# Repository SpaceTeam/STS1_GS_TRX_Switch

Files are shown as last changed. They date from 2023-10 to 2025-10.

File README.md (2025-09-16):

# Ground Station TRX Switch

This boards provides sequencing and switching for transmit and receive path of a satellite groundstation based on two galvanically isolated inputs.  
It features an on-board LNA with filter and pre and post filtering for an external power amplifier.  
It also provides ~30V switched for the PA derived from one common 48V supply.

It is controlled by an Arduino Nano which is used for timing.
It features two high-side MOSFET outputs for enabling a PA and LNA and three coaxial relays for RX/TX switching and antenna grounding (when neither RX nor TX is enabled).

The design was built for around 435MHz but probably is easy to adapt to different frequencies up to 3GHz.

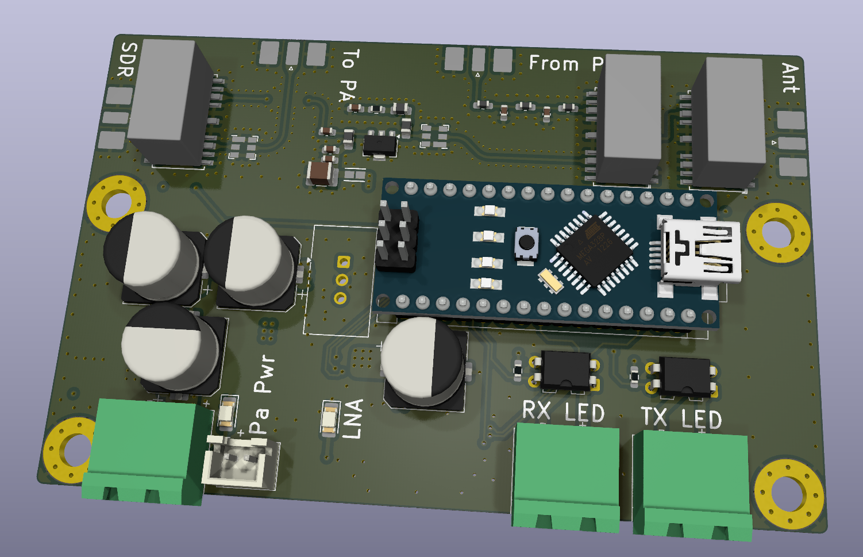
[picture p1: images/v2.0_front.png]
v2.0 Front side 3D render

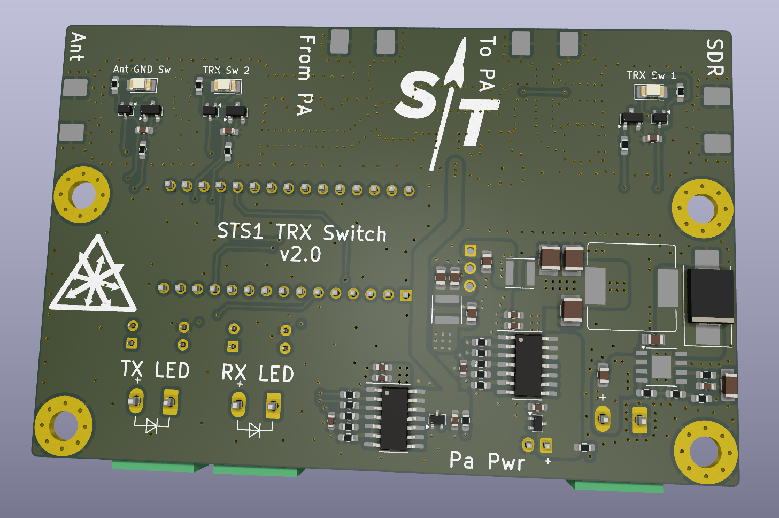
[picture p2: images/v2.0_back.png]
v2.0 Back side 3D render


## Ordering

The RF design is built for the "standard" 1.6mm thick JLCPCB 4-layer stackup consisting of the following layers:
- 35µm Outer copper
- 210.4µm Prepreg (7628, RC 49%, 8.6mil)
- 15.2µm Inner copper
- 1.065mm Core
- 15.2µm Inner copper
- 210.4µm Prepreg (7628, RC 49%, 8.6mil)
- 35µm Outer copper

For finish please choose ENIG.

## License
All files in this repository are licensed under the MIT license EXCEPT for the files in the `/3d` directory.

- Arduino Nano: By Andrew Whitham (https://grabcad.com/library/arduino-nano--1), noncommercial public use allowed (https://help.grabcad.com/article/246-how-can-models-be-used-and-shared?locale=en)
- TE HF3-53: Copyright TE Connectivity (https://www.te.com/usa-en/product-1462051-2.html)
- Molex 73251-2120: Copyright Molex LLC (https://www.molex.com/en-us/products/part-detail/0732512120)

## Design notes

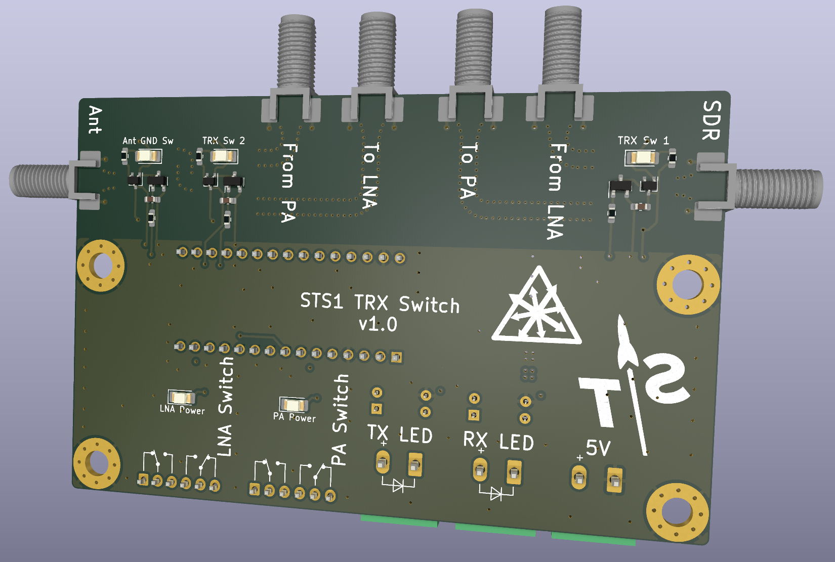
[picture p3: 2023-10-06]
images/v1.0_back.png

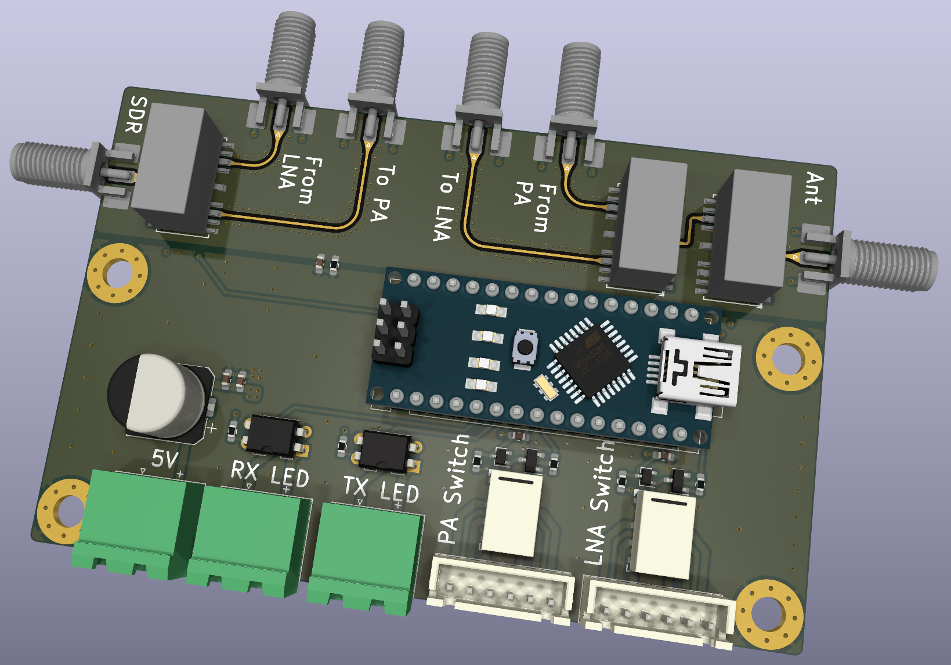
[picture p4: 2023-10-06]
images/v1.0_front.png

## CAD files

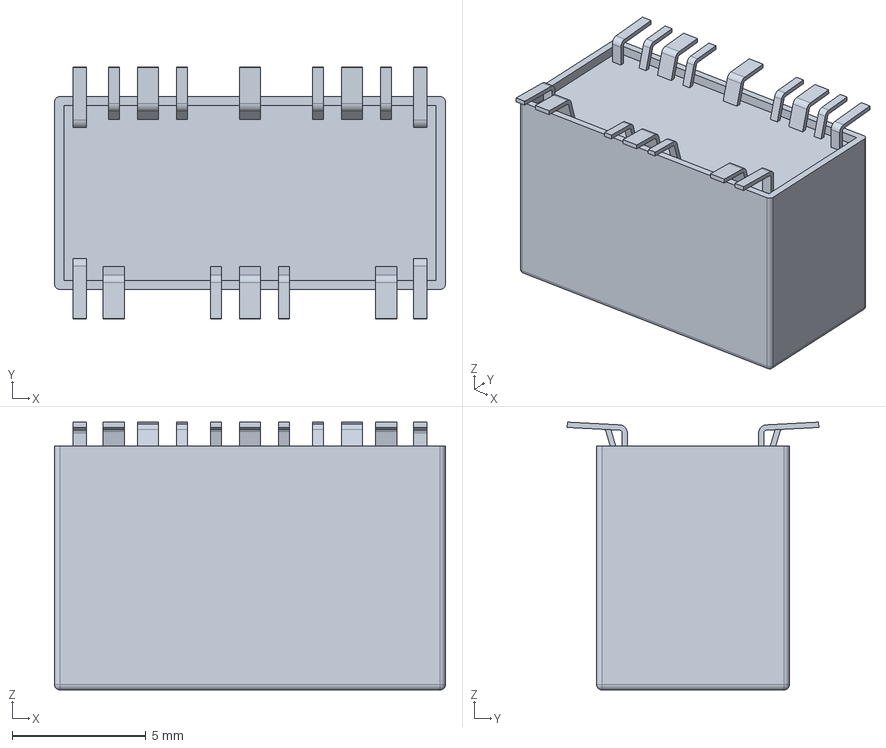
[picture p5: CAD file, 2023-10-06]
3d/TE_HF3-53.stp
14.6 x 9.40 x 10.0 mm

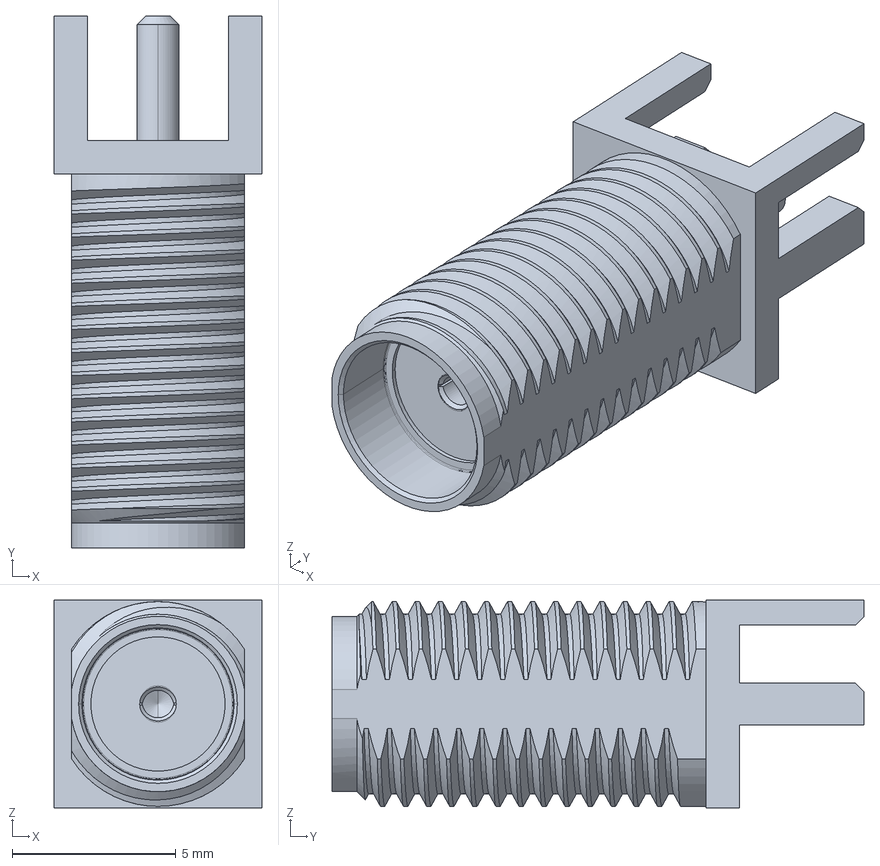
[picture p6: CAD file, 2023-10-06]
3d/Molex_732512120.stp
6.35 x 16.3 x 6.35 mm

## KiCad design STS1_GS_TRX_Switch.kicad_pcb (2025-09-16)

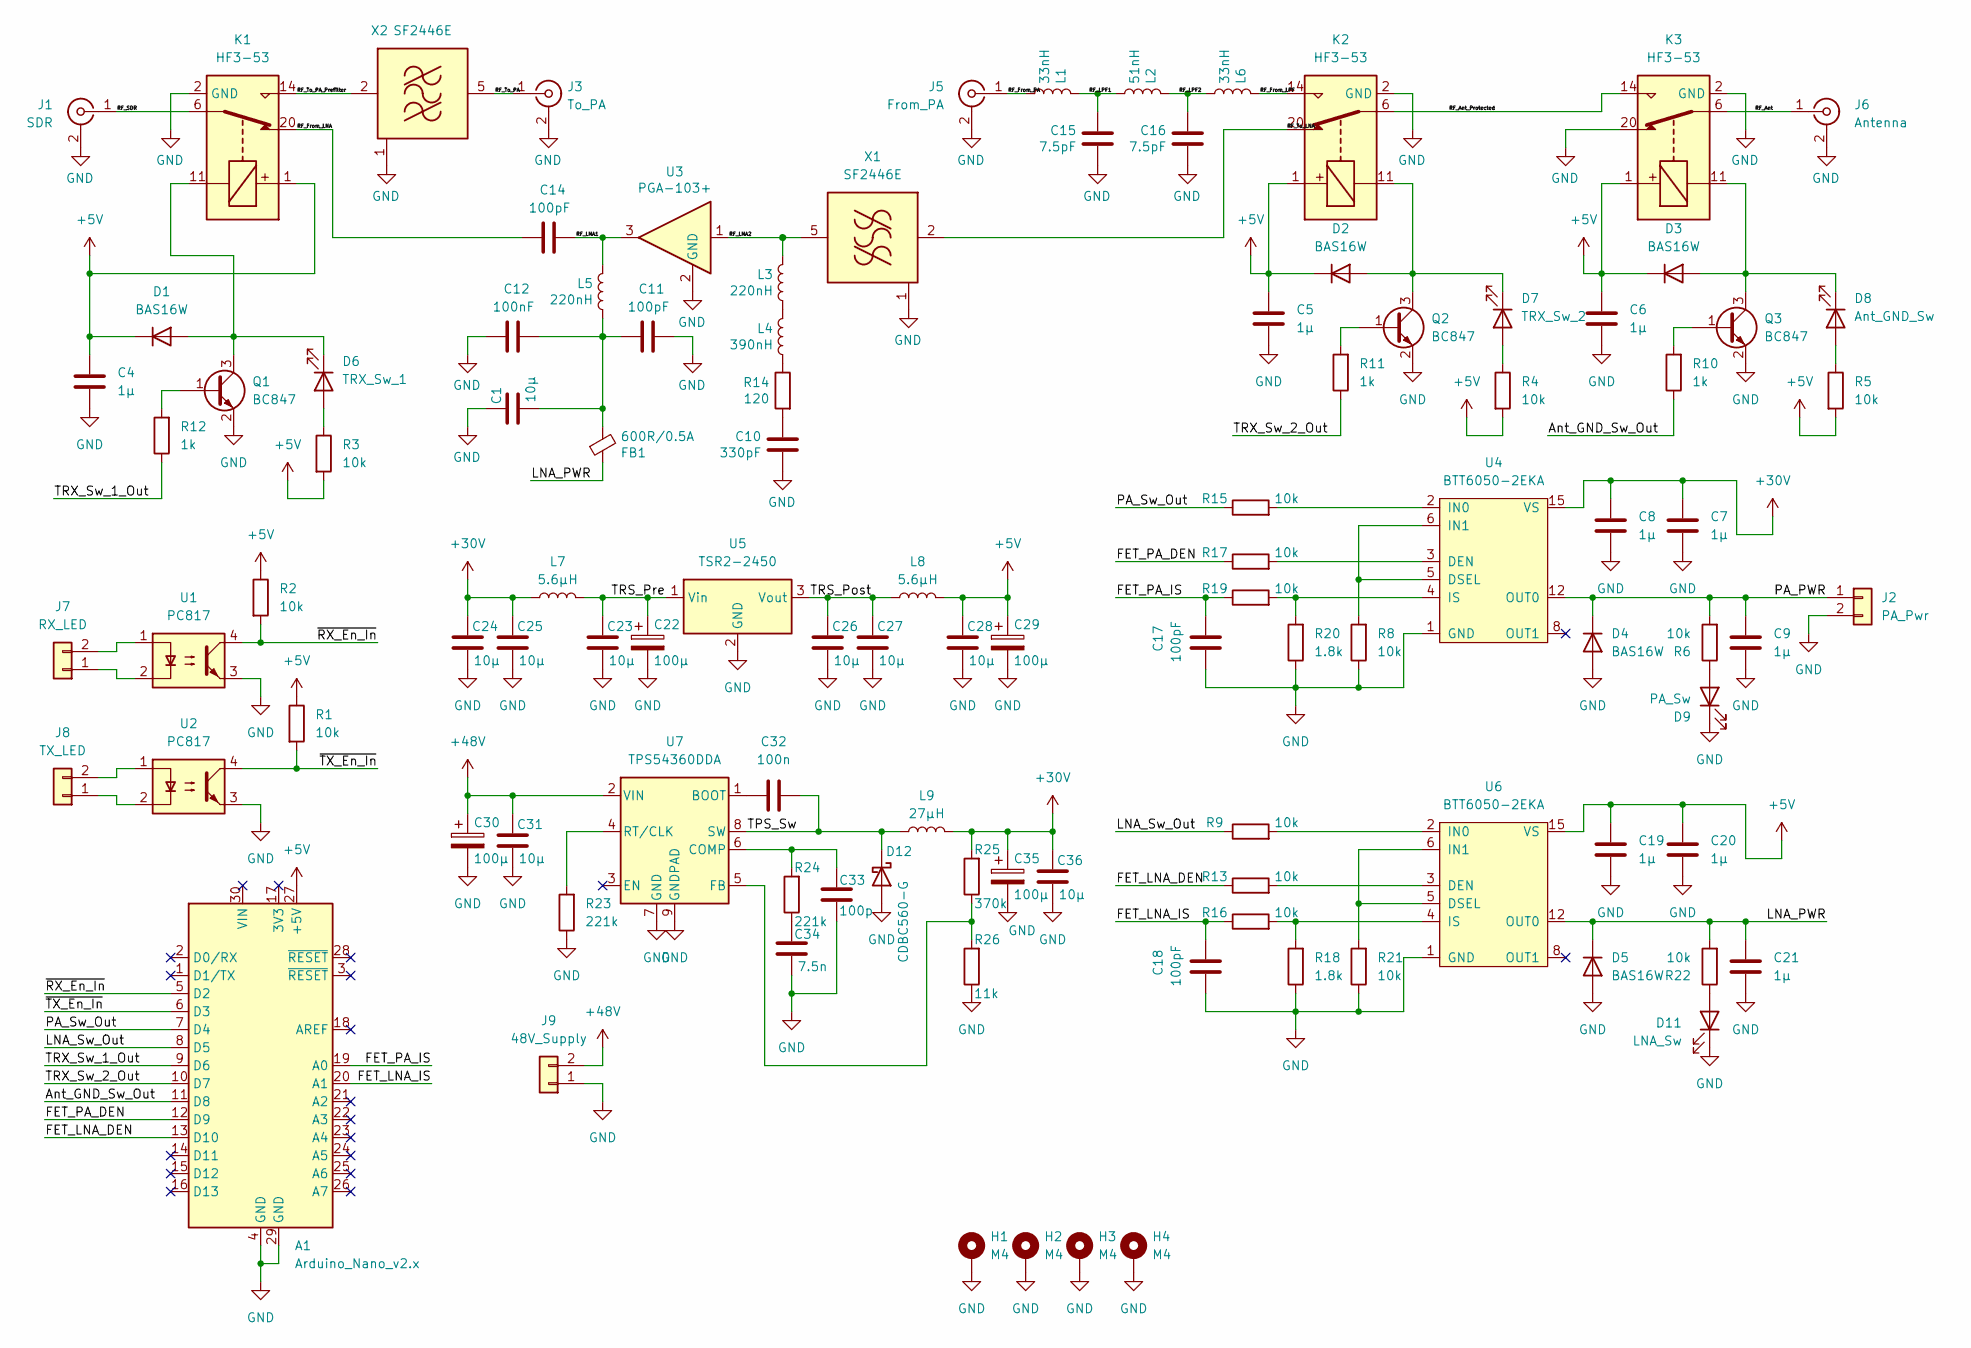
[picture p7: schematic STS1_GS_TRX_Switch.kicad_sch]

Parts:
A1: Arduino_Nano_v2.x; Arduino_Nano
C1, C24, C25, C36: 10µ; C_1210_3225Metric_Pad1.33x2.70mm_HandSolder
C4, C5, C6, C7, C8, C9, C19, C20, C21: 1µ; C_0603_1608Metric_Pad1.08x0.95mm_HandSolder
C10: 330pF; C_0603_1608Metric
C11, C14, C17, C18: 100pF; C_0603_1608Metric
C12: 100nF; C_0603_1608Metric
C15, C16: 7.5pF; C_0603_1608Metric
C22, C29, C30, C35: 100µ; CP_Elec_10x10
C23, C26, C27, C28, C31: 10µ; C_0805_2012Metric_Pad1.18x1.45mm_HandSolder
C32: 100n; C_0805_2012Metric_Pad1.18x1.45mm_HandSolder
C33: 100p; C_0603_1608Metric_Pad1.08x0.95mm_HandSolder
C34: 7.5n; C_1206_3216Metric_Pad1.33x1.80mm_HandSolder
D1, D2, D3, D4, D5: BAS16W; SOT-323_SC-70
D6: TRX_Sw_1; LED_1206_3216Metric_Pad1.42x1.75mm_HandSolder
D7: TRX_Sw_2; LED_1206_3216Metric_Pad1.42x1.75mm_HandSolder
D8: Ant_GND_Sw; LED_1206_3216Metric_Pad1.42x1.75mm_HandSolder
D9: PA_Sw; LED_1206_3216Metric_Pad1.42x1.75mm_HandSolder
D11: LNA_Sw; LED_1206_3216Metric_Pad1.42x1.75mm_HandSolder
D12: CDBC560-G; D_SMC_Handsoldering; MPN CDBC560-G
FB1: 600R/0.5A; Murata-BLM18-0.15-t0.8-0-0-IPC_A
H1, H2, H3, H4: M4; MountingHole_4.3mm_M4_Pad_Via
J1: SDR; SMA_Molex_73251-2120_EdgeMount_Horizontal
J2: PA_Pwr; JST_XH_B2B-XH-A_1x02_P2.50mm_Vertical
J3: To_PA; SMA_Molex_73251-2120_EdgeMount_Horizontal
J5: From_PA; SMA_Molex_73251-2120_EdgeMount_Horizontal
J6: Antenna; SMA_Molex_73251-2120_EdgeMount_Horizontal
J7: RX_LED; PhoenixContact_MSTBA_2,5_2-G-5,08_1x02_P5.08mm_Horizontal
J8: TX_LED; PhoenixContact_MSTBA_2,5_2-G-5,08_1x02_P5.08mm_Horizontal
J9: 48V_Supply; PhoenixContact_MSTBA_2,5_2-G-5,08_1x02_P5.08mm_Horizontal
K1, K2, K3: HF3-53; Relay_SPDT_AXICOM_HF3Series_50ohms_Pitch1.27mm
L1, L6: 33nH; L_0603_1608Metric_Pad1.05x0.95mm_HandSolder; MPN LQW18AN33NJ80D
L2: 51nH; L_0603_1608Metric_Pad1.05x0.95mm_HandSolder; MPN LQW18AN51NG80D
L3, L5: 220nH; L_0805_2012Metric; MPN LQW2BASR22J00L
L4: 390nH; L_0805_2012Metric; MPN LQW2BASR39J00L
L7, L8: 5.6µH; L_Abracon_ASPI-4030S; MPN ASPI-4030S-5R6M-T
L9: 27µH; L_Bourns_SRR1210A; MPN SRR1210-270M
Q1, Q2, Q3: BC847; SOT-23
R1, R2, R3, R4, R5, R6, R8, R9, R13, R15, R16, R17, R19, R21, R22: 10k; R_0603_1608Metric_Pad0.98x0.95mm_HandSolder
R10, R11, R12: 1k; R_0603_1608Metric_Pad0.98x0.95mm_HandSolder
R14: 120; R_0603_1608Metric
R18, R20: 1.8k; R_0603_1608Metric_Pad0.98x0.95mm_HandSolder
R23, R24: 221k; R_0603_1608Metric_Pad0.98x0.95mm_HandSolder
R25: 370k; R_0603_1608Metric_Pad0.98x0.95mm_HandSolder
R26: 11k; R_0603_1608Metric_Pad0.98x0.95mm_HandSolder
U1, U2: PC817; DIP-4_W7.62mm
U3: PGA-103+; SOT-89-3
U4, U6: BTT6050-2EKA; Infineon_PG-DSO-14-40-EP_3.9x8.65mm_P1.27mm
U5: TSR2-2450; Converter_DCDC_TRACO_TSR2-xxxx_THT
U7: TPS54360DDA; TI_SO-PowerPAD-8_ThermalVias
X1, X2: SF2446E; Filter_SAW-6_3.0x3.0mm

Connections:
+5V: A1.27 (+5V), C4.1, C5.1, C6.1, C19.1, C20.1, C28.1, C29.1, D1.3 (K), D2.3 (K), D3.3 (K), K1.1, K2.1, K3.1, L8.2, R1.1, R2.1, R3.2, R4.2, R5.2, U6.15 (VS)
+30V: C7.1, C8.1, C24.1, C25.1, C35.1, C36.1, L7.1, L9.2, R25.2, U4.15 (VS)
+48V: C30.1, C31.1, J9.2, U7.2 (VIN)
/Ant_GND_Sw_Out: A1.11 (D8), R10.1
/FET_LNA_DEN: A1.13 (D10), R13.1
/FET_LNA_IS: A1.20 (A1), C18.1, R16.1
/FET_PA_DEN: A1.12 (D9), R17.1
/FET_PA_IS: A1.19 (A0), C17.1, R19.1
/LNA_PWR: C21.1, D5.3 (K), FB1.1, R22.2, U6.12 (OUT0), U6.13 (OUT0), U6.14 (OUT0)
/LNA_Sw_Out: A1.8 (D5), R9.1
/PA_PWR: C9.1, D4.3 (K), J2.1, R6.2, U4.12 (OUT0), U4.13 (OUT0), U4.14 (OUT0)
/PA_Sw_Out: A1.7 (D4), R15.1
/RF_Ant: J6.1 (In), K3.6
/RF_Ant_Protected: K2.6, K3.14
/RF_From_LNA: C14.2, K1.20
/RF_From_LPF: K2.14, L6.1
/RF_From_PA: J5.1 (In), L1.2
/RF_LNA1: C14.1, L5.1, U3.3
/RF_LNA2: L3.1, U3.1, X1.5 (OUT)
/RF_LPF1: C15.1, L1.1, L2.2
/RF_LPF2: C16.1, L2.1, L6.2
/RF_SDR: J1.1 (In), K1.6
/RF_To_LNA: K2.20, X1.2 (IN)
/RF_To_PA: J3.1 (In), X2.5 (OUT)
/RF_To_PA_Prefilter: K1.14, X2.2 (IN)
/TPS_Sw: C32.2, D12.1 (K), L9.1, U7.8 (SW)
/TRS_Post: C26.1, C27.1, L8.1, U5.3 (Vout)
/TRS_Pre: C22.1, C23.1, L7.2, U5.1 (Vin)
/TRX_Sw_1_Out: A1.9 (D6), R12.1
/TRX_Sw_2_Out: A1.10 (D7), R11.1
/~RX_En_In: A1.5 (D2), R2.2, U1.4
/~TX_En_In: A1.6 (D3), R1.2, U2.4
GND: A1.4 (GND), A1.29 (GND), C1.1, C4.2, C5.2, C6.2, C7.2, C8.2, C9.2, C10.2, C11.1, C12.2, C15.2, C16.2, C17.2, C18.2, C19.2, C20.2, C21.2, C22.2, C23.2, C24.2, C25.2, C26.2, C27.2, C28.2, C29.2, C30.2, C31.2, C33.2, C34.2, C35.2, C36.2, D4.1 (A), D5.1 (A), D9.1 (K), D11.1 (K), D12.2 (A), H1.1, H2.1, H3.1, H4.1, J1.2 (Ext), J2.2, J3.2 (Ext), J5.2 (Ext), J6.2 (Ext), J9.1, K1.2 (GND), K1.5 (GND), K1.7 (GND), K1.10 (GND), K1.12 (GND), K1.13 (GND), K1.15 (GND), K1.17 (GND), K1.19 (GND), K1.21 (GND), K1.22 (GND), K2.2 (GND), K2.5 (GND), K2.7 (GND), K2.10 (GND), K2.12 (GND), K2.13 (GND), K2.15 (GND), K2.17 (GND), K2.19 (GND), K2.21 (GND), K2.22 (GND), K3.2 (GND), K3.5 (GND), K3.7 (GND), K3.10 (GND), K3.12 (GND), K3.13 (GND), K3.15 (GND), K3.17 (GND), K3.19 (GND), K3.20, K3.21 (GND), K3.22 (GND), Q1.2 (E), Q2.2 (E), Q3.2 (E), R8.1, R18.1, R20.1, R21.1, R23.1, R26.1, U1.3, U2.3, U3.2 (GND), U4.1 (GND), U5.2 (GND), U6.1 (GND), U7.7 (GND), U7.9 (GNDPAD), X1.1 (GND), X1.3 (GND), X1.4 (GND), X1.6 (GND), X2.1 (GND), X2.3 (GND), X2.4 (GND), X2.6 (GND)
unnamed: C1.2, C11.2, C12.1, FB1.2, L5.2
unnamed: C10.1, R14.2
unnamed: C34.1, R24.1
unnamed: D1.1 (A), D6.1 (K), K1.11, Q1.3 (C)
unnamed: D2.1 (A), D7.1 (K), K2.11, Q2.3 (C)
unnamed: D3.1 (A), D8.1 (K), K3.11, Q3.3 (C)
unnamed: D6.2 (A), R3.1
unnamed: D7.2 (A), R4.1
unnamed: D8.2 (A), R5.1
unnamed: D9.2 (A), R6.1
unnamed: D11.2 (A), R22.1
unnamed: J7.1, U1.2
unnamed: J7.2, U1.1
unnamed: J8.1, U2.2
unnamed: J8.2, U2.1
unnamed: L3.2, L4.1
unnamed: L4.2, R14.1
unnamed: Q1.1 (B), R12.2
unnamed: Q2.1 (B), R11.2
unnamed: Q3.1 (B), R10.2
unnamed: R17.2, U4.3 (DEN)
unnamed: R8.2, U4.5 (DSEL), U4.6 (IN1)
unnamed: R15.2, U4.2 (IN0)
unnamed: R19.2, R20.2, U4.4 (IS)
unnamed: R13.2, U6.3 (DEN)
unnamed: R21.2, U6.5 (DSEL), U6.6 (IN1)
unnamed: R9.2, U6.2 (IN0)
unnamed: R16.2, R18.2, U6.4 (IS)
unnamed: C32.1, U7.1 (BOOT)
unnamed: C33.1, R24.2, U7.6 (COMP)
unnamed: R25.1, R26.2, U7.5 (FB)
unnamed: R23.2, U7.4 (RT/CLK)

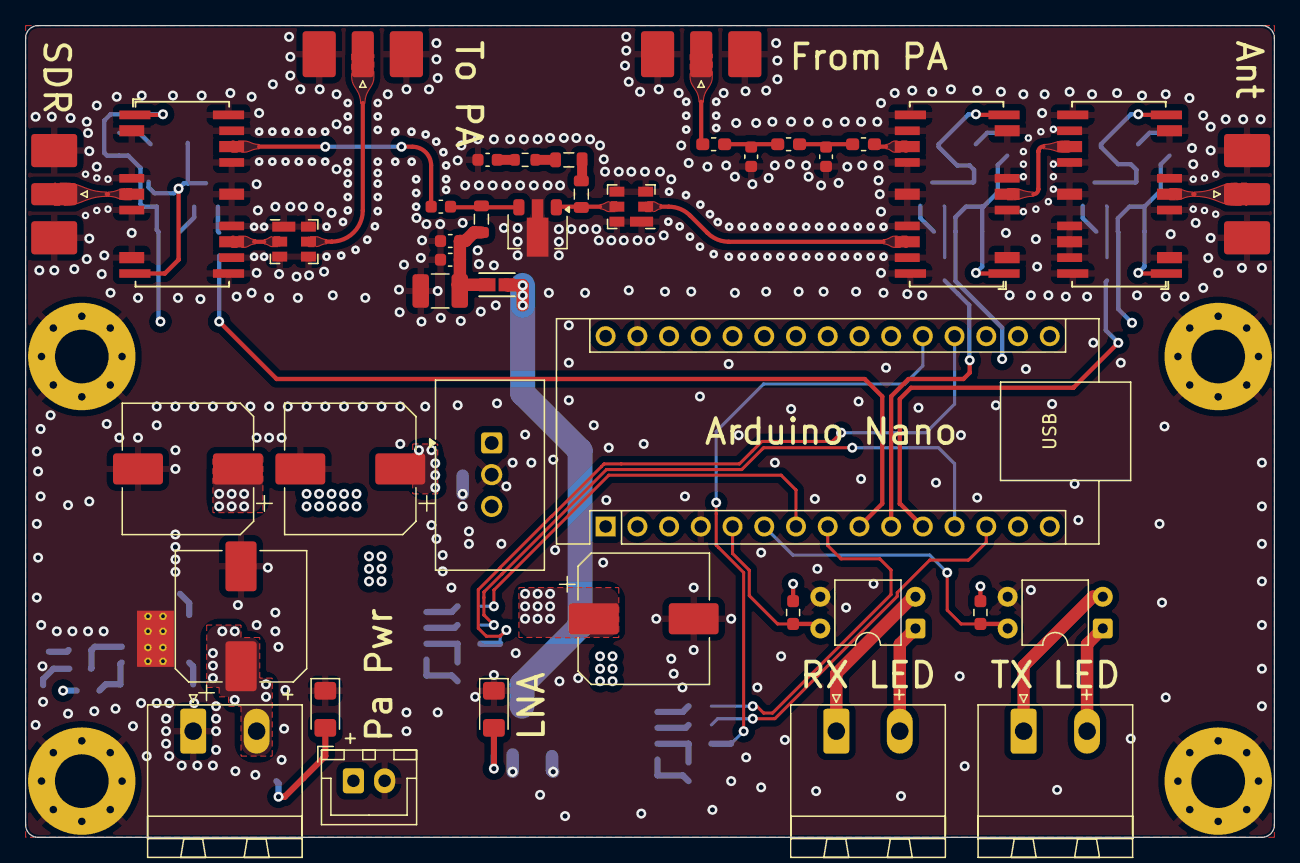
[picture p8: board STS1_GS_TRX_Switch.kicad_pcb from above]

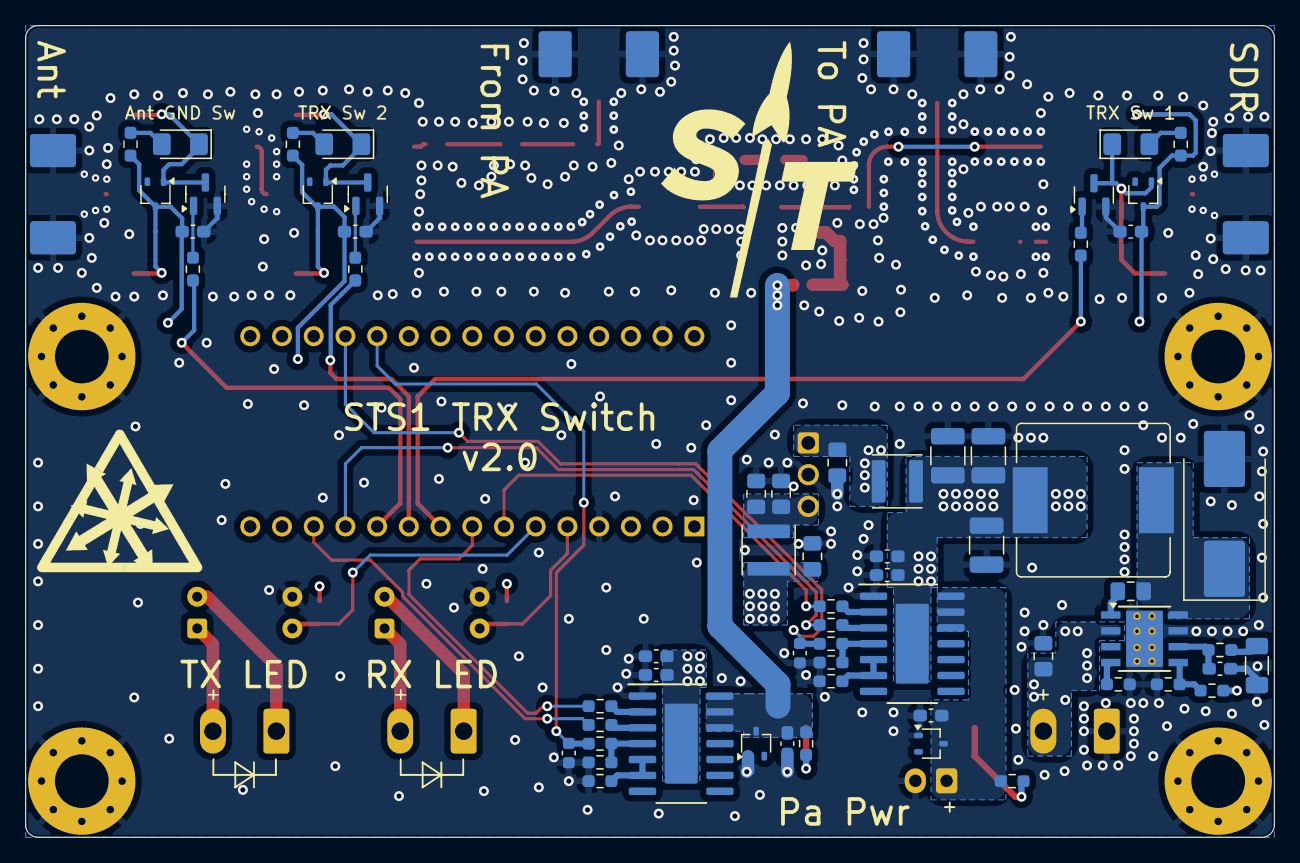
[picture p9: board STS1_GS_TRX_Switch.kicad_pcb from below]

Board: 4 copper layers, 100.0 x 65.0 mm, 107 parts (62 on the bottom side), 65 nets.

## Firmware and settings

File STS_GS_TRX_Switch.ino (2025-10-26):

const int rxLedIn = 2;
const int txLedIn = 3;
const int lnaEnableOut = 5;
const int paEnableOut = 4;
const int antGroundOut = 8;
const int antTrxSwitch1Out = 6;
const int antTrxSwitch2Out = 7;
const int lnaDiagnosticEnable = 10;
const int paDiagnosticEnable = 9;
const int lnaCurrentIn = A1;
const int paCurrentIn = A0;

// Maximum operation time of TE HF3 relays is 5ms.
// Maximum release time is 6ms.
// Exit time is mostly impacted by how long the LNA/PA take to "wind down" after power supply is cut.
const unsigned long rxEnterMillis = 25;
const unsigned long rxExitMillis = 15;
const unsigned long txEnterMillis = 15;
const unsigned long txExitMillis = 100;
const unsigned long minInvalidMillis = 50;

enum state_t {
  IDLE,
  RX_ENTER,
  RX,
  RX_EXIT,
  TX_ENTER,
  TX,
  TX_EXIT,
  INVALID
};

state_t state = IDLE;
state_t old_state = IDLE;
bool state_changed = false;

unsigned long stateEnter = millis();

void setup() {
  pinMode(lnaEnableOut, OUTPUT);
  pinMode(paEnableOut, OUTPUT);
  pinMode(antGroundOut, OUTPUT);
  pinMode(antTrxSwitch1Out, OUTPUT);
  pinMode(antTrxSwitch2Out, OUTPUT);

  pinMode(rxLedIn, INPUT);
  pinMode(txLedIn, INPUT);

  Serial.begin(115200);
}

void loop() {
  bool rx = !digitalRead(rxLedIn);
  bool tx = !digitalRead(txLedIn);
  old_state = state;

  switch (state) {
    case IDLE:
      digitalWrite(lnaEnableOut, LOW);
      digitalWrite(paEnableOut, LOW);
      digitalWrite(antGroundOut, LOW);
      digitalWrite(antTrxSwitch1Out, LOW);
      digitalWrite(antTrxSwitch2Out, LOW);

      if (rx) state = RX_ENTER;
      else if (tx) state = TX_ENTER;
      break;
    case RX_ENTER:
      digitalWrite(lnaEnableOut, LOW);
      digitalWrite(paEnableOut, LOW);
      digitalWrite(antGroundOut, HIGH);
      digitalWrite(antTrxSwitch1Out, LOW);
      digitalWrite(antTrxSwitch2Out, LOW);

      if (state_changed) stateEnter = millis();

      if (tx) state = RX_EXIT;
      else if (!rx) state = RX_EXIT;
      else if (millis() - stateEnter > rxEnterMillis) state = RX;

      break;
    case RX:
      digitalWrite(lnaEnableOut, HIGH);
      digitalWrite(paEnableOut, LOW);
      digitalWrite(antGroundOut, HIGH);
      digitalWrite(antTrxSwitch1Out, LOW);
      digitalWrite(antTrxSwitch2Out, LOW);

      if (tx) state = RX_EXIT;
      else if (!rx) state = RX_EXIT;

      break;
    case RX_EXIT:
      digitalWrite(lnaEnableOut, LOW);
      digitalWrite(paEnableOut, LOW);
      digitalWrite(antGroundOut, HIGH);
      digitalWrite(antTrxSwitch1Out, LOW);
      digitalWrite(antTrxSwitch2Out, LOW);

      if (state_changed) stateEnter = millis();

      if (tx && (millis() - stateEnter > rxExitMillis)) state = TX_ENTER;
      else if (rx && (millis() - stateEnter > rxEnterMillis)) state = RX;
      else if (!rx && (millis() - stateEnter > rxExitMillis)) state = IDLE;

      break;
    case TX_ENTER:
      digitalWrite(lnaEnableOut, LOW);
      digitalWrite(paEnableOut, LOW);
      digitalWrite(antGroundOut, HIGH);
      digitalWrite(antTrxSwitch1Out, HIGH);
      digitalWrite(antTrxSwitch2Out, HIGH);

      if (state_changed) stateEnter = millis();

      if (!tx) state = TX_EXIT;
      else if (millis() - stateEnter > txEnterMillis) state = TX;

      break;
    case TX:
      digitalWrite(lnaEnableOut, LOW);
      digitalWrite(paEnableOut, HIGH);
      digitalWrite(antGroundOut, HIGH);
      digitalWrite(antTrxSwitch1Out, HIGH);
      digitalWrite(antTrxSwitch2Out, HIGH);

      if (!tx) state = TX_EXIT;

      break;
    case TX_EXIT:
      digitalWrite(lnaEnableOut, LOW);
      digitalWrite(paEnableOut, LOW);
      digitalWrite(antGroundOut, HIGH);
      digitalWrite(antTrxSwitch1Out, HIGH);
      digitalWrite(antTrxSwitch2Out, HIGH);

      if (state_changed) stateEnter = millis();

      if (tx && (millis() - stateEnter > txEnterMillis)) state = TX;
      else if (!tx && (millis() - stateEnter > txExitMillis)) state = IDLE;

      break;
    case INVALID:
    default:
      // Switch to "TX Mode" but don't enable the PA
      digitalWrite(lnaEnableOut, LOW);
      digitalWrite(paEnableOut, LOW);
      digitalWrite(antGroundOut, HIGH);
      digitalWrite(antTrxSwitch1Out, HIGH);
      digitalWrite(antTrxSwitch2Out, HIGH);

      if (state_changed) stateEnter = millis();

      if ((!(rx && tx)) && (millis() - stateEnter > minInvalidMillis)) state == IDLE;

      break;
  }

  state_changed = old_state != state;
}

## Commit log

2023-10-06 feat: initial commit
    [Molex_732512120.stp, STS1_GS_TRX_Switch.kicad_pcb, STS1_GS_TRX_Switch.kicad_sch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]
2023-10-06 fix: Logo was flipped
    [STS1_GS_TRX_Switch.kicad_pcb]
2025-06-14 fix: wrong polarity of one of the RF relays
    [STS1_GS_TRX_Switch.kicad_pcb, STS1_GS_TRX_Switch.kicad_sch]
2025-09-16 feat: v2.0 with built-in LNA, PA-pre-filter and PA output filter
    [STS1_GS_TRX_Switch.kicad_pcb, STS1_GS_TRX_Switch.kicad_sch]
2025-10-09 feat: add arduino sketch
2025-10-26 fix: increase delays to prevent LNA from oscillating on turn on because of an open input
    [STS_GS_TRX_Switch.ino]
